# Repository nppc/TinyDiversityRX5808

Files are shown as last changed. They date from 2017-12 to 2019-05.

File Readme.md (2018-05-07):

# Tiny 5.8GHz Diversity VRX for EV100 Goggles
Sample video, showing diversity in work (for example at 1:42).

Recording taken with [Eachine Pro DVR integrated in to the EV100 goggles](https://github.com/nppc/VideoSwitchDVR).

IMAGE ALT TEXT HERE (https://youtu.be/wFIAKiWohQQ)

3D rendering of the board:

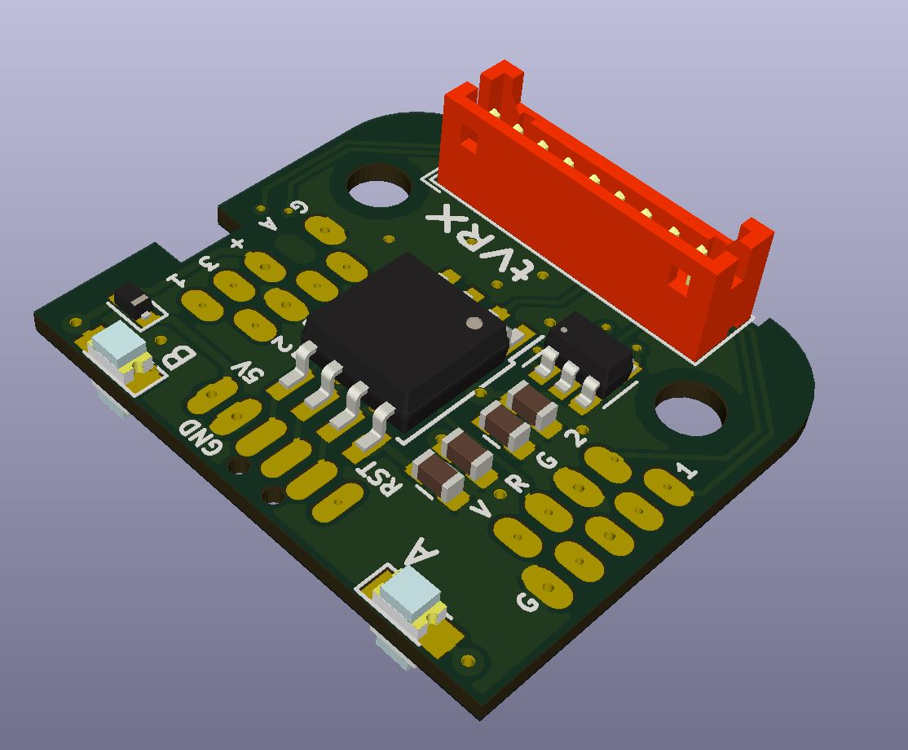
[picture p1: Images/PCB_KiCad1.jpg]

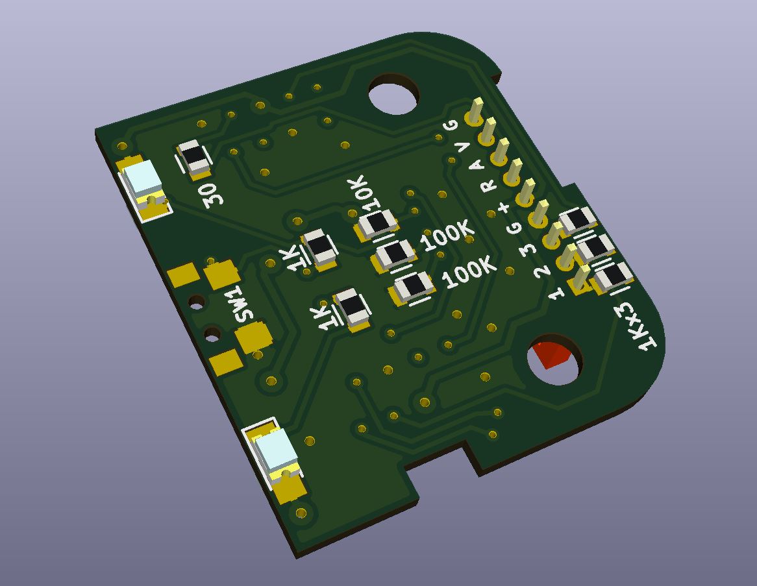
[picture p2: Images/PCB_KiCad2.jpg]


PCB can be ordered here: https://oshpark.com/shared_projects/An2v0djk

## Proof of concept
- Diversity bench test: https://www.youtube.com/watch?v=jwpYg-zWEIs
- Band/channel change and auto-search test: https://www.youtube.com/watch?v=jH8NeLfK5f4

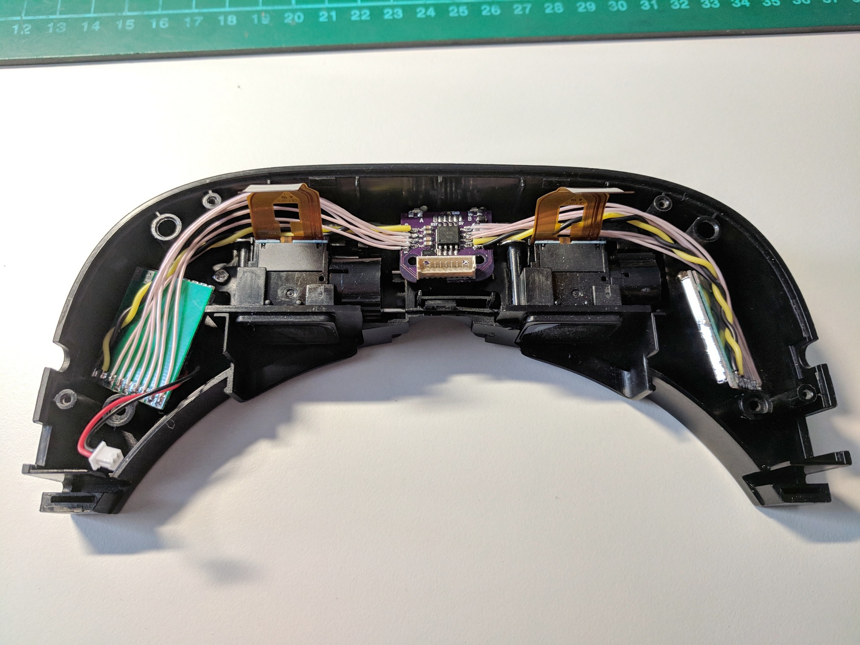
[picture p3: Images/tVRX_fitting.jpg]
EV100 Inside


## Calibration
- Power OFF VTX.
- Power ON Goggles and then press button on tVRX.
- LEDs will make 5 short (100ms) blinks indicating, that lowest video signal detection in progress.
- When LEDs will stay lit, then power ON VTX.
- After about 2 seconds LEDs will make 5 long (900ms) blinks indicating that highest video signal detection in progress.
- When LEDs turn OFF for 2 seconds, then Calibration is done.
- Now tVRX will exit from Calibration mode and go to normal state.

## Compiling
Use latest Arduino IDE.
You need to add ATtiny Support to Arduino IDE (Google the Internet). :)
In Arduino IDE Clock should be left as default = 1MHz (internal).
In this project we don't use Arduino bootloader. So, you need to export compiled binary from IDE and flash it with external programmer like USBasp.
Programming pads on tVRX:
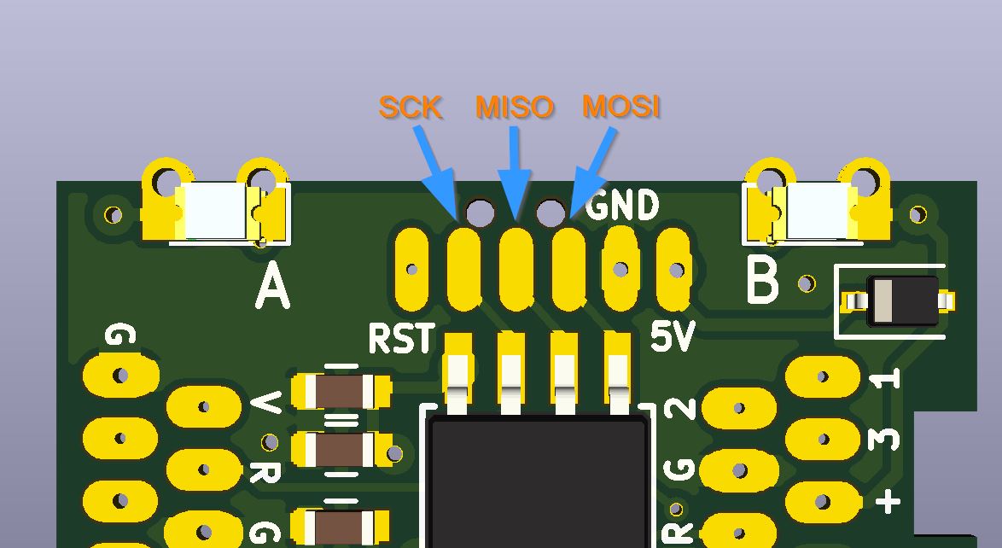
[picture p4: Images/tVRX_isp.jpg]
tVRX ISP

All fuses leave default.

Discussion on RCG: https://www.rcgroups.com/forums/showthread.php?3051872-DIY-Tiny-Diversity-VRX-for-EV100-Goggles

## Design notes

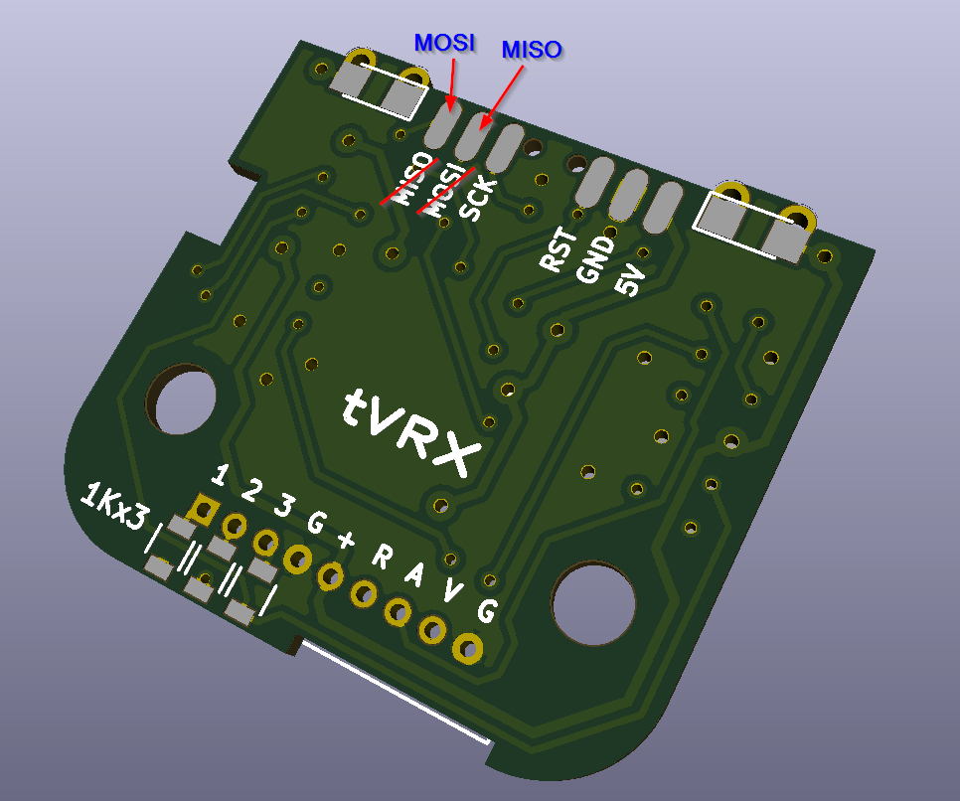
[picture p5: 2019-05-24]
Images/Silk_wrong.png

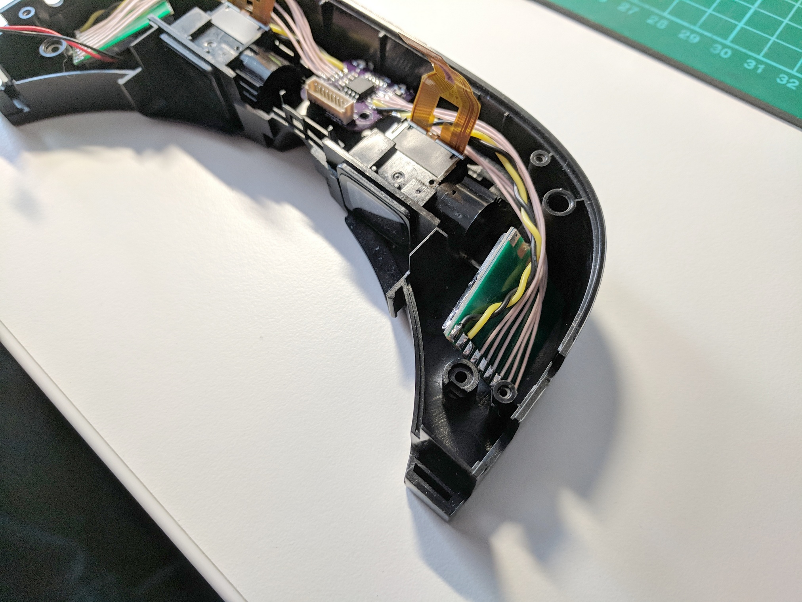
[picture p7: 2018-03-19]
Images/tVRX_right_receiver.jpg

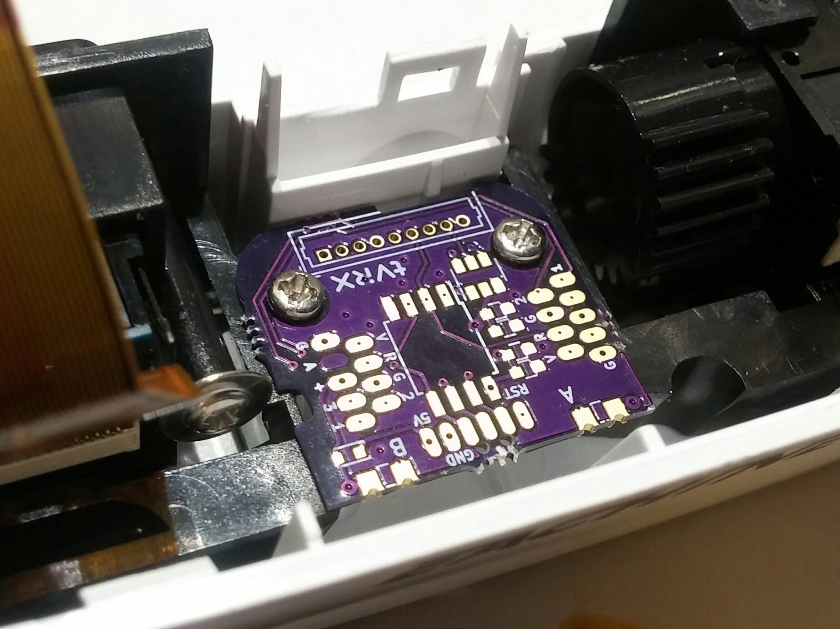
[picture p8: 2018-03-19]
Images/tVRX_PCB.jpg

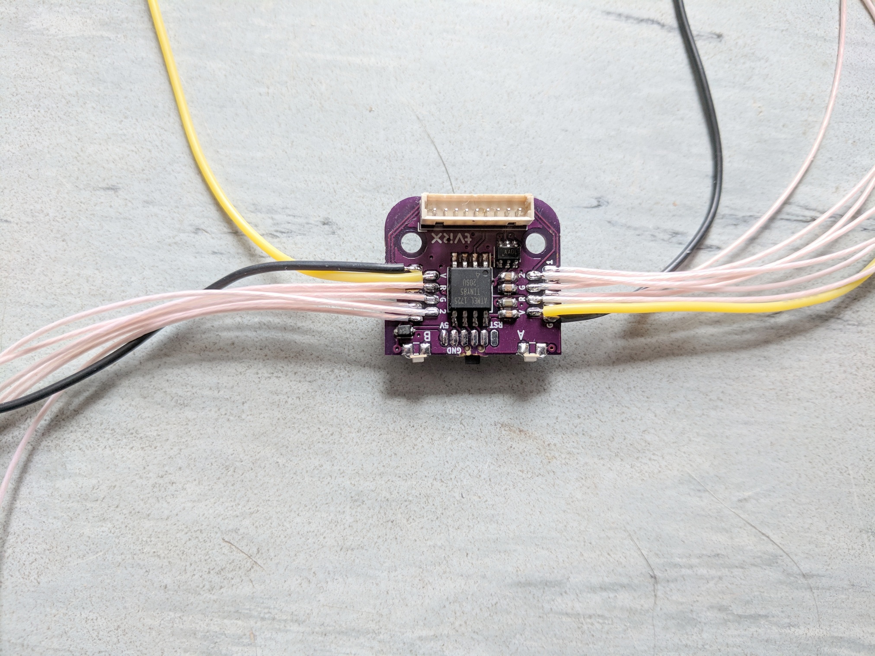
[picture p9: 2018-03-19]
Images/tVRX_harness_00.jpg

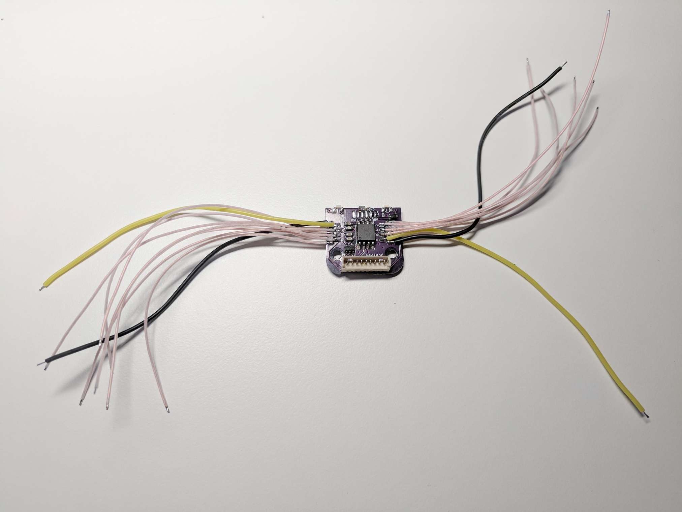
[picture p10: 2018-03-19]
Images/tVRX_harness_01.jpg

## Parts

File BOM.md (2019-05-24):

## Bill of Materials

Ref | Value | size/footprint | Mouser part no
-------- | ---------------- | ---------- | ----------
U1 | MAX4624 | SOT-23-6 | 700-MAX4624EUTT
U2 | ATTINY25, ATTINY45 or ATTINY85 | SOIC8 | 556-ATTINY85-20SU
R1,R2,R3 | 1K | 0603 | 603-RC0603FR-071KL
R4,R5 | 100K | 0603 | 603-RC0603FR-07100KL
R6,R7 | 560-1K | 0603 | 603-RC0603FR-071KL
R8 | 30 | 0603 | 603-RC0603FR-0730RL
R9 | 10K | 0603 | 603-RC0603FR-0710KL
C1, C3 | 100n | 0603 | 710-885012105016
C2 | 10n | 0603 | 710-885012206014
C4 | 10uf | 0603 | 710-885012106006
D1,D2 | LED | 0805 | 710-150080GS75000
D3 | B5819WS (or any) | SOD-323 | 833-B5819WS-TP
Button | 6mm X 7.3mm | https://www.banggood.com/50Pcs-2x4x3_5mm-Tact-Tactile-Push-Button-Switch-SMD-Surface-Mount-Momentary-p-1007736.html

Looks like U1 can be replaced with STG719 if MAX4624 is not available. This is not tested, but footprint is 1 to 1. The resistance is different (4 instead of 1 Ohm).

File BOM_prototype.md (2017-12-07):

## Bill of Materials

Ref | Value | size/footprint
-------- | ---------------- | ----------
U1 | MAX4624 | SOT-23-6
U2 | ATTINY85-20SU | SOIC8
U3 | MAX4625 | SOT-23-6
R1,R2,R3 | 1K | 0603
R4,R5 | 100K | 0603
R6,R8 | 560-1K | 1206
R7 | 30 | 1206
R9 | 10K | 0603
C1, C3,C5 | 100n | 0603
C2,C6 | 10n | 0603
C4 | 10uf | 0603
D1,D2 | LED | 0805
D3 | 1N5819HW (or any) | SOD-123
Button | 6mm X 7.3mm

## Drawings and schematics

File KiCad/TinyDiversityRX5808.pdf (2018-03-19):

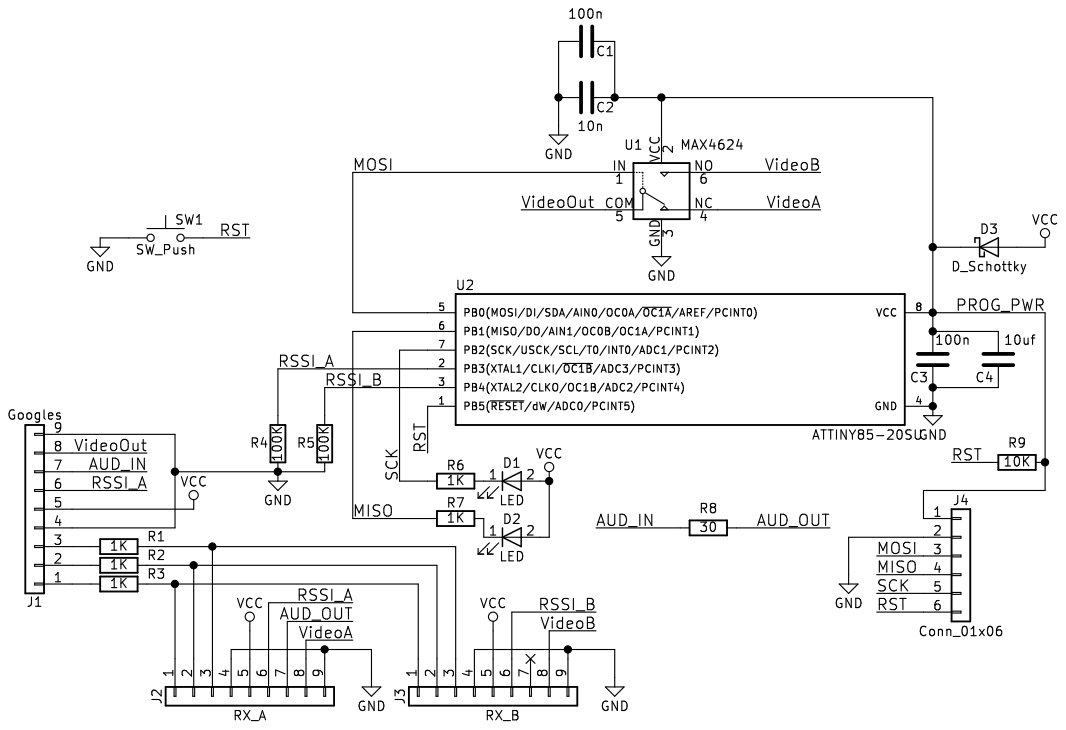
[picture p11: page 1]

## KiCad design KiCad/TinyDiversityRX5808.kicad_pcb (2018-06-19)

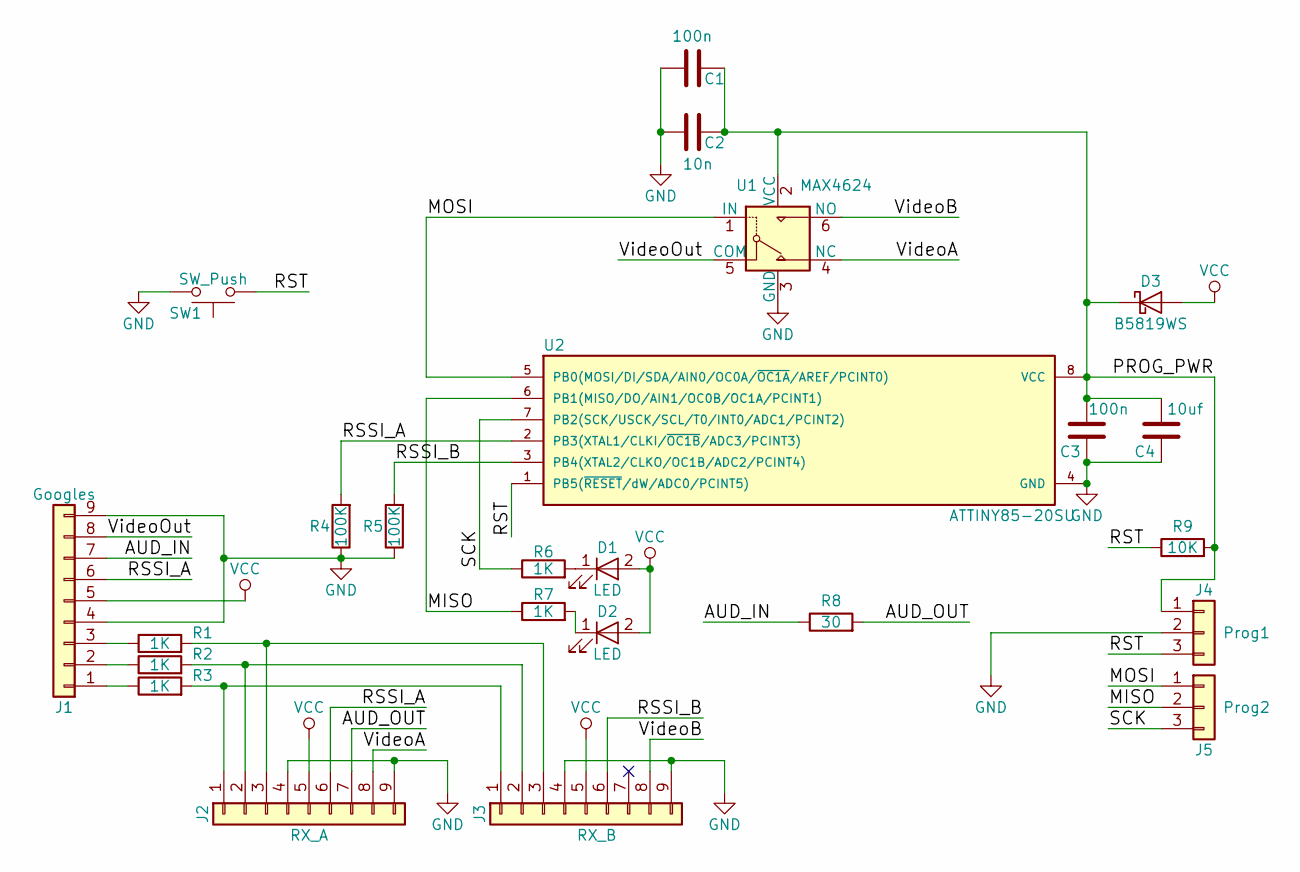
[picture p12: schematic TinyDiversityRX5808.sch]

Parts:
C1, C3: 100n; C_0603
C2: 10n; C_0603
C4: 10uf; C_0603
D1, D2: LED; LED_0805
D3: B5819WS; D_SOD-323
J1: Googles; Molex_PicoBlade_53047-0910_09x1.25mm_Straight
J2: RX_A; Molex_PicoBlade_53048-0910_09x1.25mm_Angled
J3: RX_B; Molex_PicoBlade_53048-0910_09x1.25mm_Angled
J4: Prog1; Pads_prog_3pin1.25mm
J5: Prog2; Pads_prog_3pin1.25mm
R1, R2, R3, R6, R7: 1K; R_0603
R4, R5: 100K; R_0603
R8: 30; R_0603
R9: 10K; R_0603
SW1: SW_Push; Button_TS-018
U1: MAX4624; SOT-23-6
U2: ATTINY85-20SU; SOIJ-8_5.3x5.3mm_Pitch1.27mm

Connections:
/AUD_IN: J1.7, R8.1
/AUD_OUT: J2.7, R8.2
/MISO: J5.2, R7.1, U2.6 (PB1(MISO/DO/AIN1/OC0B/OC1A/PCINT1))
/MOSI: J5.1, U1.1 (IN), U2.5 (PB0(MOSI/DI/SDA/AIN0/OC0A/~OC1A~/AREF/P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)
/PROG_PWR: C1.1, C2.1, C3.2, C4.2, D3.1 (K), J4.1, R9.2, U1.2 (VCC), U2.8 (VCC)
/RSSI_A: J1.6, J2.6, R4.2, U2.2 (PB3(XTAL1/CLKI/~OC1B~/ADC3/PCINT3))
/RSSI_B: J3.6, R5.2, U2.3 (PB4(XTAL2/CLKO/OC1B/ADC2/PCINT4))
/RST: J4.3, R9.1, SW1.1, U2.1 (PB5(~RESET~/dW/ADC0/PCINT5))
/SCK: J5.3, R6.1, U2.7 (PB2(SCK/USCK/SCL/T0/INT0/ADC1/PCINT2))
/VideoA: J2.8, U1.4 (NC)
/VideoB: J3.8, U1.6 (NO)
/VideoOut: J1.8, U1.5 (COM)
GND: C1.2, C2.2, C3.1, C4.1, J1.4, J1.9, J2.4, J2.9, J3.4, J3.9, J4.2, R4.1, R5.1, SW1.2, U1.3 (GND), U2.4 (GND)
unnamed 13: D1.1 (K), R6.2; also elsewhere on the board
unnamed 14: D2.1 (K), R7.2; also elsewhere on the board
unnamed: J1.1, R3.1
unnamed: J1.2, R2.1
unnamed: J1.3, R1.1
unnamed: J2.1, J3.1, R3.2
unnamed: J2.2, J3.2, R2.2
unnamed: J2.3, J3.3, R1.2
VCC: D1.2 (A), D2.2 (A), D3.2 (A), J1.5, J2.5, J3.5; also elsewhere on the board

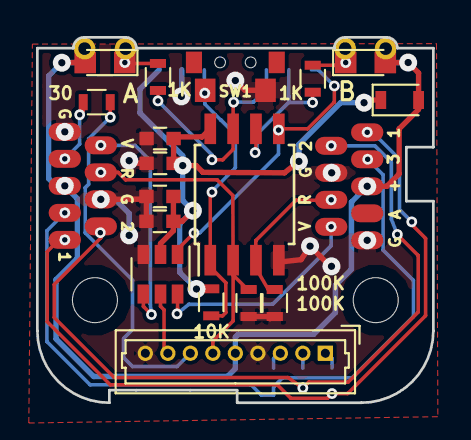
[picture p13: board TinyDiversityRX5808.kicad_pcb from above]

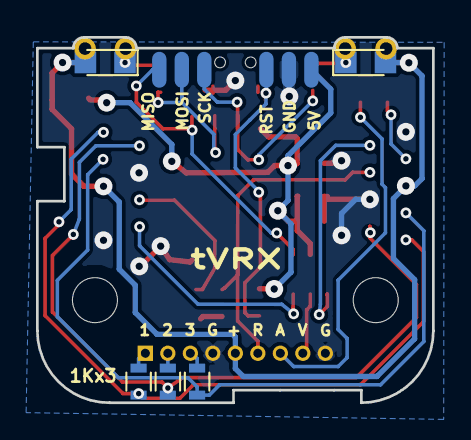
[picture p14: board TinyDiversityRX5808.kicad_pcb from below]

Board: 2 copper layers, 22.0 x 20.3 mm, 26 parts (7 on the bottom side), 22 nets.

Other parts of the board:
D1#2, D2#2: LED; LED_0805

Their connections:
unnamed 13: D1#2.1; also elsewhere on the board
unnamed 14: D2#2.1; also elsewhere on the board
VCC: D1#2.2, D2#2.2; also elsewhere on the board

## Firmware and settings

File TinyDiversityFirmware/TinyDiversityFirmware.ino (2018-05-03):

//#define DEBUG


#include <EEPROM.h>

//#define MIN_TUNE_TIME 25 // update RSSI values every 25ms

// RSSI strength should be greater than the value below (percent) over the
// other receiver before we switch. This prevents flicker when RSSI values
// are close
#define DIVERSITY_HYSTERESIS 2

// How long (ms) the RSSI strength has to have a greater difference than the
// above before switching.
#define DIVERSITY_HYSTERESIS_PERIOD 100

// Calibration for Max RSSI value will start 
// after the RSSI ADC value will be higher than 
// min RSSI ADC value plus CALIBRATION_ADC_DIFFERENCE.
#define CALIBRATION_ADC_DIFFERENCE 100


#define PIN_SWITCH_VIDEO 	0	//PB0
#define PIN_LED_A 			2 	//PB2
#define PIN_LED_B 			1	//PB1
#define PIN_RSSI_A 			A3	//PB3
#define PIN_RSSI_B 			A2	//PB4

// don't use first byte of EEPROM. It can be corrupted
#define EEPROM_RESET_FLAG_ADDR	5	// RESET Flag (byte)
#define EEPROM_MIN_RSSI_A_ADDR	7	// RSSI RAW Calibration value (int)
#define EEPROM_MAX_RSSI_A_ADDR	9	// RSSI RAW Calibration value (int)
#define EEPROM_MIN_RSSI_B_ADDR	11	// RSSI RAW Calibration value (int)
#define EEPROM_MAX_RSSI_B_ADDR	13	// RSSI RAW Calibration value (int)

#define INTERNAL2V56_NO_CAP (6)

uint8_t activeReceiver;
uint8_t diversityTargetReceiver;

typedef struct {
  int min;
  int max;
  int raw;
  uint8_t mapped;
} RSSI;

RSSI rssiA;
RSSI rssiB;

unsigned long diversityHysteresisTimer;


enum ReceiverSelect: byte {RX_A, RX_B};

// some macros
#define LED_A_ON bitClear(PORTB, PIN_LED_A) // LED A ON
#define LED_B_ON bitClear(PORTB, PIN_LED_B) // LED B ON
#define LED_A_OFF bitSet(PORTB, PIN_LED_A) // LED A OFF
#define LED_B_OFF bitSet(PORTB, PIN_LED_B) // LED B OFF


void setupPins() {
	bitSet(DDRB, PIN_SWITCH_VIDEO);
	bitSet(DDRB, PIN_LED_A);
	bitSet(DDRB, PIN_LED_B);
	LED_A_OFF;
	LED_B_OFF;
}

void setup()
{
	// First lets read RESET Flag; Power (bit0), Reset (bit 1), etc
	uint8_t RESET_value = MCUSR;
	MCUSR = 0;	// reset flag for nect use
	
	//analogReference(INTERNAL2V56_NO_CAP);
	analogReference(INTERNAL);	// 1.1v
	
	setupPins();

	uint8_t last_RESET_value = EEPROM.read(EEPROM_RESET_FLAG_ADDR);
	EEPROM.update(EEPROM_RESET_FLAG_ADDR, RESET_value);	// Only update if value is changed

	// should we enter calibration mode
	if(bitRead(last_RESET_value,1)!=1 && bitRead(RESET_value,1)==1){
		// enter Calibration Mode
		doCalibration();
		EEPROM.update(EEPROM_RESET_FLAG_ADDR, 1); //clear RESET flag to enter calibration mode after new RESET
	}
	// should we abort calibration mode
	if(bitRead(last_RESET_value,1)==1 && bitRead(RESET_value,1)==1){
		// abort Calibration Mode
		EEPROM.update(EEPROM_RESET_FLAG_ADDR, 1); //clear RESET flag to enter calibration mode after new RESET
	}

    setActiveReceiver(RX_A);
	diversityTargetReceiver = activeReceiver;	// Initialize variable for diversity switching
	
	readEEPROMSettings();
	updateRssi();	// Initialize variables

}

void setActiveReceiver(ReceiverSelect Set_RX){
	activeReceiver = Set_RX;
	if(activeReceiver == RX_A){
		bitClear(PORTB, PIN_SWITCH_VIDEO);
		LED_A_ON;
		LED_B_OFF;
	}else{
		bitSet(PORTB, PIN_SWITCH_VIDEO);
		LED_A_OFF;
		LED_B_ON;
	}
}

uint8_t remapRawRssiValue(RSSI rssi) {
  return constrain(map(rssi.raw, rssi.min, rssi.max, 0, 100), 0, 100);
}

void updateRssi() {
	analogRead(PIN_RSSI_A); // Fake read to let ADC settle.
	rssiA.raw = analogRead(PIN_RSSI_A);
	rssiA.mapped = remapRawRssiValue(rssiA);
 
	analogRead(PIN_RSSI_B); // Fake read to let ADC settle.
	rssiB.raw = analogRead(PIN_RSSI_B);
	rssiB.mapped = remapRawRssiValue(rssiB);
}
	
void switchDiversity() {

	int8_t rssiDiff = (int8_t) rssiA.mapped - (int8_t) rssiB.mapped;
	uint8_t rssiDiffAbs = abs(rssiDiff);
	uint8_t currentBestReceiver;
	uint8_t nextReceiver;
	
	nextReceiver = activeReceiver;

	if (rssiDiff > 0) {
		currentBestReceiver = RX_A;
	} else if (rssiDiff < 0) {
		currentBestReceiver = RX_B;
	} else {
		currentBestReceiver = activeReceiver;
	}

	if (rssiDiffAbs >= DIVERSITY_HYSTERESIS) {
		if (currentBestReceiver == diversityTargetReceiver) {
			if ((diversityHysteresisTimer+DIVERSITY_HYSTERESIS_PERIOD)<millis()) {
				nextReceiver = diversityTargetReceiver;
			}
		} else {
			diversityTargetReceiver = currentBestReceiver;
			diversityHysteresisTimer=millis();
		}
	} else {
		diversityHysteresisTimer=millis();
	}

	setActiveReceiver(nextReceiver);

}
	
void loop() {
    // Update RSSI values as fast as possible.
	updateRssi();
	switchDiversity(); // Will switch only if signals are significantly different and difference stays for a while.
}

void readEEPROMSettings(){
	rssiA.min=readEEPROMint(EEPROM_MIN_RSSI_A_ADDR);
	rssiA.max=readEEPROMint(EEPROM_MAX_RSSI_A_ADDR);
	rssiB.min=readEEPROMint(EEPROM_MIN_RSSI_B_ADDR);
	rssiB.max=readEEPROMint(EEPROM_MAX_RSSI_B_ADDR);
}

int readEEPROMint(uint8_t addr){
	return EEPROM.read(addr)+EEPROM.read(addr+1)*256;
}

void writeEEPROMint(uint8_t addr, uint16_t value){
	EEPROM.update(addr, lowByte(value));
	EEPROM.update(addr+1, highByte(value));
}

void doCalibration(){

#if defined(DEBUG)
	// switch video source every 4 seconds in DEBUG mode
	while(1==1){
		mDelay(4000);
		setActiveReceiver(RX_A);
		mDelay(4000);
		setActiveReceiver(RX_B);

/*
		// show ADC values divided by 20.
		int tmp;
		mDelay(2000);
		LED_A_ON;
		LED_B_ON;
		mDelay(700);
		LED_A_OFF;
		LED_B_OFF;
		mDelay(2000);
		updateRssi();
		tmp = rssiA.raw / 64;
		for(int i=0;i<tmp;i++){
			LED_A_ON;
			mDelay(100);
			LED_A_OFF;
			mDelay(400);
		}
		mDelay(2000);
		updateRssi();
		tmp = rssiB.raw / 64;
		for(int i=0;i<tmp;i++){
			LED_B_ON;
			mDelay(100);
			LED_B_OFF;
			mDelay(400);
		}
*/
	}

#else
	// Calibration routine
	// 1. Wait for lowest RSSI while some period (short blinks). Record min value.
	// 2. Now LEDs are ON. Wait for VTX powered ON. 
	// 3. If RSSI changed dramatically, then wait 2 seconds (LEDs are ON).
	// 4. Wait for highest RSSI while some period (long blinks). Record max value.
	// 5. Store calibration data in EEPROM (LEDs are OFF).
	unsigned long tmr_tmp;
	int curMinRSSIA=1023; // max 10 bit ADC value is 1023
	int curMinRSSIB=1023; // max 10 bit ADC value is 1023
	int curMaxRSSIA=0;
	int curMaxRSSIB=0;
	// 5 short blinks for capturing low signal
	for(uint8_t i=0;i<5;i++){
		LED_A_ON;
		LED_B_ON;
		mDelay(100);
		LED_A_OFF;
		LED_B_OFF;
		tmr_tmp = millis();
		while((tmr_tmp+700)>millis()){
			updateRssi();	// refresh RSSI RAW values
			if(rssiA.raw<curMinRSSIA)curMinRSSIA = rssiA.raw;
			if(rssiB.raw<curMinRSSIB)curMinRSSIB = rssiB.raw;
		}
	}
	// Now wait until RSSI will jump for a good degree (CALIBRATION_ADC_DIFFERENCE ADC values) for both receivers
	LED_A_ON;
	LED_B_ON;
	while((rssiA.raw<curMinRSSIA+CALIBRATION_ADC_DIFFERENCE) || (rssiB.raw<curMinRSSIB+CALIBRATION_ADC_DIFFERENCE)){
		mDelay(100);
		updateRssi();
	}
	mDelay(2000); // Delay for 2 seconds for VTX stabilize
	// 5 long blinks for capturing high signal
	for(uint8_t i=0;i<5;i++){
		LED_A_ON;
		LED_B_ON;
		tmr_tmp = millis();
		while((tmr_tmp+900)>millis()){
			updateRssi();	// refresh RSSI RAW values
			if(rssiA.raw>curMaxRSSIA)curMaxRSSIA = rssiA.raw;
			if(rssiB.raw>curMaxRSSIB)curMaxRSSIB = rssiB.raw;
		}
		LED_A_OFF;
		LED_B_OFF;
		mDelay(100);
	}
	// Now it is time to store values to EEPROM
	writeEEPROMint(EEPROM_MIN_RSSI_A_ADDR,curMinRSSIA);
	writeEEPROMint(EEPROM_MAX_RSSI_A_ADDR,curMaxRSSIA);
	writeEEPROMint(EEPROM_MIN_RSSI_B_ADDR,curMinRSSIB);
	writeEEPROMint(EEPROM_MAX_RSSI_B_ADDR,curMaxRSSIB);
	mDelay(2000);	// wait before exit from Calibration

#endif
}

void mDelay(int dtmp){
	unsigned long tmp = millis();
	while((tmp+dtmp)>millis()){}
}

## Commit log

2017-11-16 Prototype board is ready
    [TinyDivercityRX5808.sch]
2017-11-17 Reworked PCB with larger gaps
    [TinyDivercityRX5808.kicad_pcb]
2017-11-17 thicker thermals
    [TinyDivercityRX5808.kicad_pcb]
2017-11-17 Mask pdf is inverted
    [TinyDivercityRX5808.kicad_pcb]
2017-11-20 Initial writeup on firmware
    [TinyDivercityRX5808.kicad_pcb]
2017-11-21 Added signal switching routine
2017-12-04 Modified test board
    [TinyDivercityRX5808.kicad_pcb, TinyDivercityRX5808.sch]
2017-12-05 Second version of prototype board is ready
    [TinyDivercityRX5808.kicad_pcb, TinyDivercityRX5808.sch]
2017-12-05 Slight asjustment to the PCB
    [TinyDivercityRX5808.kicad_pcb]
2017-12-05 Change firmware for V2 board
2017-12-07 BOM for prototype added
2017-12-20 First draft of final PCB
    [TinyDivercityRX5808.kicad_pcb, TinyDivercityRX5808.sch]
2017-12-20 Changed attiny case from QFN to SOIC8
    [TinyDivercityRX5808.kicad_pcb, TinyDivercityRX5808.sch]
2017-12-20 Ready for production version
    [TinyDivercityRX5808.kicad_pcb]
2017-12-21 Adjusted holes distance
    [TinyDivercityRX5808.kicad_pcb]
2017-12-22 Changed via drill size to 0.3mm
    [TinyDivercityRX5808.kicad_pcb]
2018-01-17 Moved 30 ohm resistor
    [TinyDivercityRX5808.kicad_pcb]
2018-03-15 Added Readme and slightly adjusted calibratin routine
2018-03-18 Rename files. Slight adjust to the readme.
    [TinyDiversityRX5808.kicad_pcb, TinyDiversityRX5808.sch]
2018-03-19 Added some more photos of PCB and EV100 assembling
2018-03-19 BOM adjusted. PCB 3d model images
2018-03-19 Restored holes for LEDs side soldering
2018-03-19 Button URL added
2018-03-19 Added circuit diagram
2018-03-19 Added PDF circuit diagram
2018-03-20 add video switch datasheet
2018-03-21 Change schottky footprint
    [TinyDiversityRX5808.kicad_pcb]
2018-03-21 Adjust link to OSHPark latest PCB
2018-05-03 some comments fixed. Thank you tun0.
    [TinyDiversityFirmware.ino]
2018-05-07 Added video sample
2018-06-18 Layout change for easier solder and more thin design
    [TinyDiversityRX5808.kicad_pcb, TinyDiversityRX5808.sch]
2018-06-19 Add panelized PCB (4x4)
    [TinyDiversityRX5808.kicad_pcb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]
2018-09-20 Added mouser codes to BOM
